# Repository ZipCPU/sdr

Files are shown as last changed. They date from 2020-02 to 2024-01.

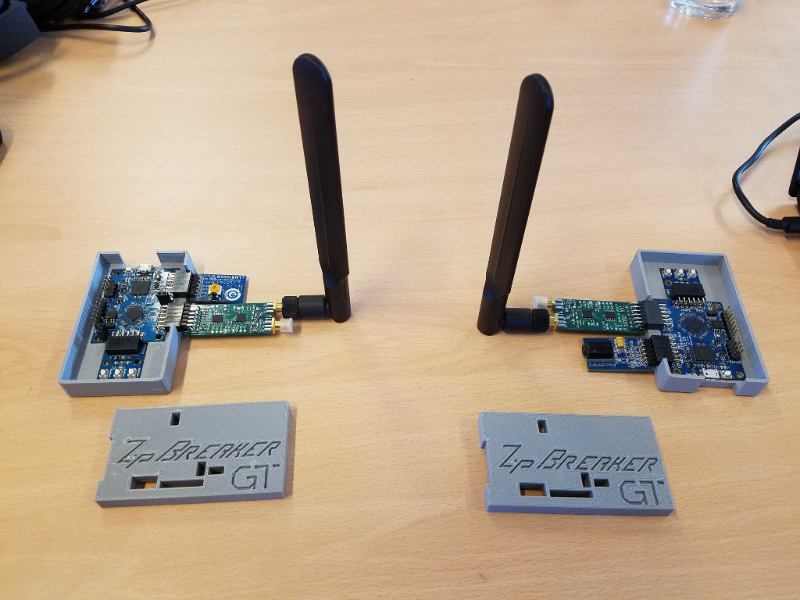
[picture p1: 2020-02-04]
doc/radio-set.jpg

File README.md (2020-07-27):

# A Software Defined Radio Project for FPGAs

Okay, so ... FPGA designs aren't really software.  Perhaps this should more
appropriately be named a "Gateware Defined Radio" project--but that spoils the
idea.

The goal of this project is to build a gateware design that can transfer audio
from one radio to another.  The design is built around the
[icebreaker](https://github.com/icebreaker-fpga/icebreaker) FPGA board,
the [SX1257 Radio PMod](https://github.com/xil-se/SX1257-PMOD),
the [Digilent MEMS microphone](https://store.digilentinc.com/pmod-mic3-mems-microphone-with-adjustable-gain/)
and the [Digilent AMP2 PMod](https://store.digilentinc.com/pmod-amp2-audio-amplifier/).
You can see [a picture of this setup here](doc/radio-set.jpg).

## Building the design

This repository actually contains several designs.  There's an
[AM transmitter](rtl/amxmit.v),
an [FM transmitter](rtl/fmxmit.v),
a [QPSK transmitter](rtl/qpskxmit.v),
an [AM receiver](rtl/amdemod.v), an
[FM receiver](rtl/fmdemod.v), and a
[QPSK receiver](rtl/qpskrcvr.v).  There are also three composed  designs, which
compose the transmitter and receiver together for simulation (only) purposes.
Which design gets built into the repository
is controlled by which "RF" line in the [AutoFPGA
Makefile](autodata/Makefile) is uncommented.

To build, you'll first need [AutoFPGA](https://github.com/ZipCPU/autofpga)
installed and in your path.  You can then run `make autodata` to build the
[top level design](rtl/toplevel.v), [PCF](rtl/sdr.pcf),
[simulation](sim/main_tb.cpp), and [software data files](sw/regdefs.h).  From
here, `make rtl` will build the design, `make sim` will build the simulator,
and `make sw` will build the host support software.

Beware, if you use any of the composed simulations, such as the AM transmitter
followed by the AM demodulator, you will run into a problem where the
microphone and the amplifier are both attempting to use the same pins.  The
solution is not to build the composed (transmit/receive) design in rtl.
Instead, run `make rtl-sim` to build the full simulation.

## Running in Simulation

To run the design in simulation, simply run the `main_tb` file in the `sim/`
directory.  This isn't very useful at present, however, unless you add the
`-d` switch to turn on VCD file generation.  You can then examine all the
traces from within the design.

Be aware, the simulation has no channel model.  Outputs to the
[SX1257](https://github.com/xil-se/SX1257-PMOD)
are simply fed back into the simulation receiver.

## Running on hardware

To run the design on an icebreaker, you can load the design via
`sudo iceprog rtl/sdr.bin`.  Once you do that, you'll want to then run
`sw/netuart /dev/ttyUSB?` (replace with your serial port device).  At this
point, you can interact with your design using `wbregs`.  Perhaps more
importantly, you can interact with the registers on the
[SX1257](https://github.com/xil-se/SX1257-PMOD)
using the `rfregs`.  In particular, `txconfig.sh` will turn the transmitter
on, and set it up at 915MHz.

## Debugging within hardware

This design offers two methods for debugging: capturing traces, and capturing
histograms from within the data flow.  Two bits of the GPIO register (three
for the TX/RX composed simulations) control a tap point selection within the
design.  This tap point contains a CE signal, 32'bits of data, and 10 bits
of data for a histogram.

To record a trace from wtihin the hardware, map the signals you wish to capture
to a Wishbone Scope C++ file--such as [this one for the
microphone](sw/micscope.cpp).  You can then use `wbregs rfscope 0` to reset
the scope any time you want to make a new capture, and
[micscope](sw/micscope.cpp) to extract the captured dasta and then to turn
it into a VCD file you can then analyze with GTKWave.

Alternatively, you can capture histograms from within the design.  These
can be read with the [histogram](sw/histogram.cpp) program.  This program will
also output a binary file of 32-bit integers containing your histogram.
(The
[histogram](https://zipcpu.com/dsp/2019/12/21/histogram.html)
is currently hardcoded at 1024 words, due to hardware limitations
in the iCE40 up5k.)

With a little creativity, the [histogram capture
utility](https://zipcpu.com/dsp/2019/12/21/histogram.html) can be turned into
a constellation capture utility.  By sending 5-bits of I and 5-bits of Q
into the histogram, and then interpreting the results accordingly, you can
capture (and then plot) a constellation diagram.  This is the purpose of
the [constellation](sw/constellation.cpp) program.

## Project Status

As of 20200204, ...

1. The AM receiver works when composed with the transmitter in simulation.
	The simulation has no channel model, is only so good, etc., etc.
	It's a start.
2. Both FM transmit/receive pair work when composed together in simulation.
3. The AM transmitter works, and the results can be heard using a Lime
	SDR radio receiver.  There's an annoying tone present which I haven't
	yet chased down.

As of 20200727, there's now a [QPSK transmitter](rtl/qpskxmit.v) and
[receiver](rtl/qpskrcvr.v) which both (roughly) work in simulation.  I say
roughly because the carrier tracking loop breaks lock even in simulation.
Further, the filters used in these designs are horrible block average types
of filters.  Hence, while the design can recover the incoming audio, there's
still lots of room for improvement.

## License

This project and all of its files are licensed under the GNU General
Public License, v3.

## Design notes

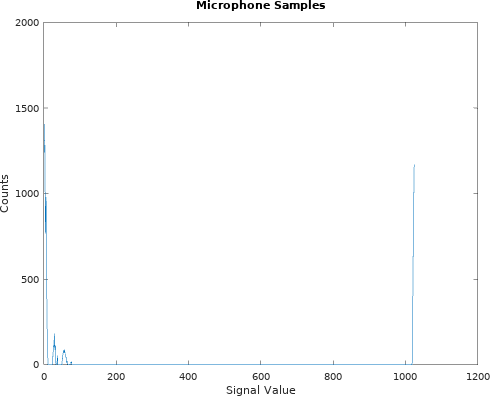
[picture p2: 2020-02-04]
doc/good-histogram.png

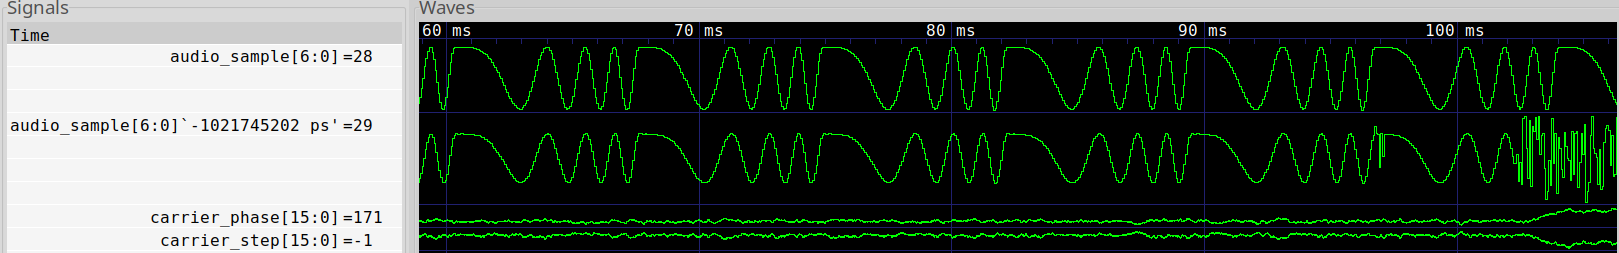
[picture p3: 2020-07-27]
doc/qpsk-matching-audio-lost-sync.png

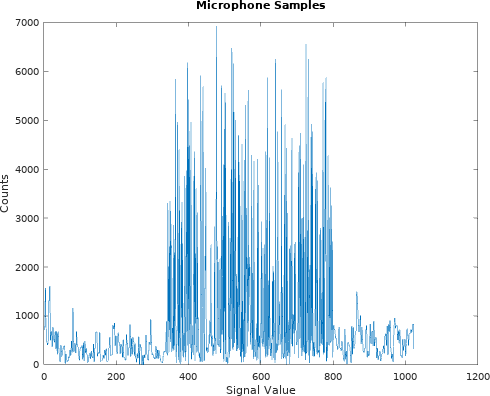
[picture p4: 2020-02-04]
doc/bad-hist-multimode.png

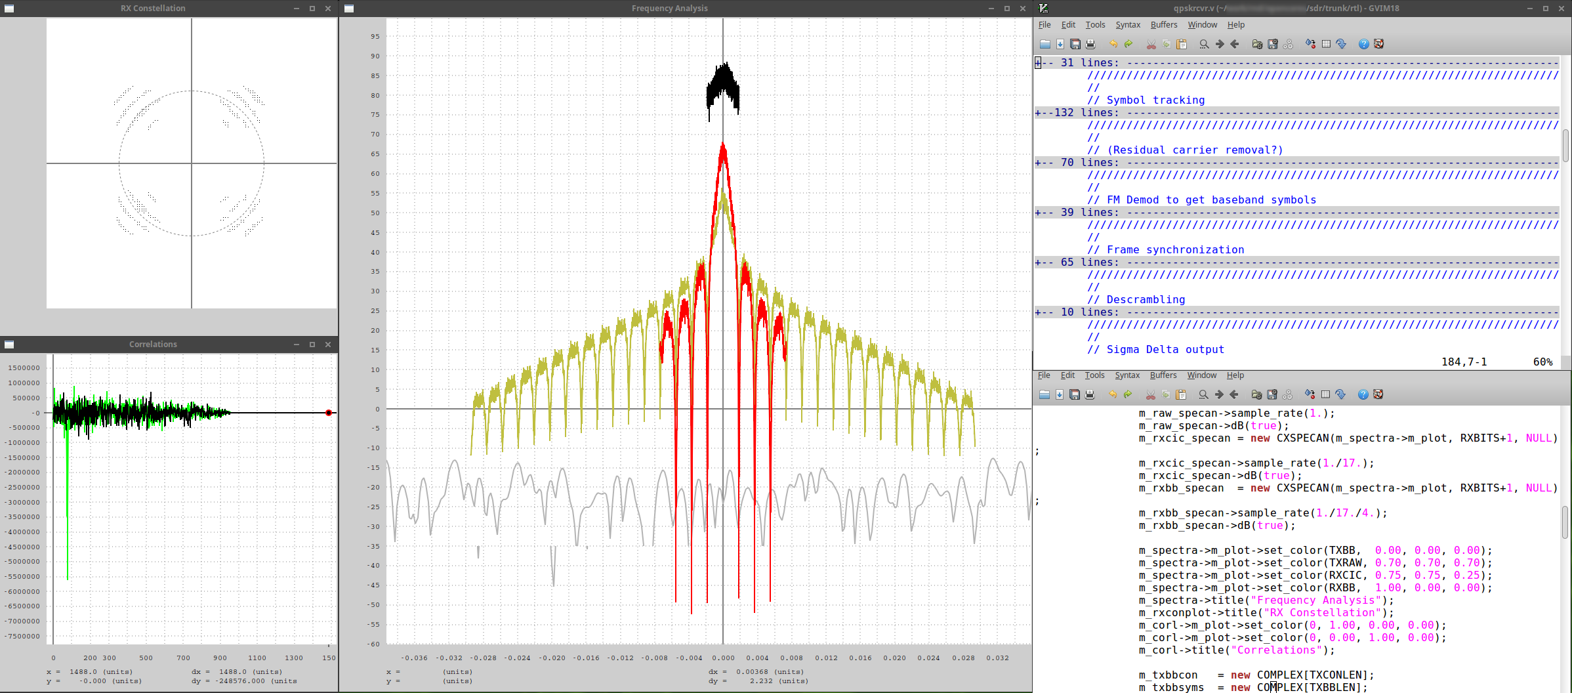
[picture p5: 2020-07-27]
doc/cooking-w-gas-screenshot.png

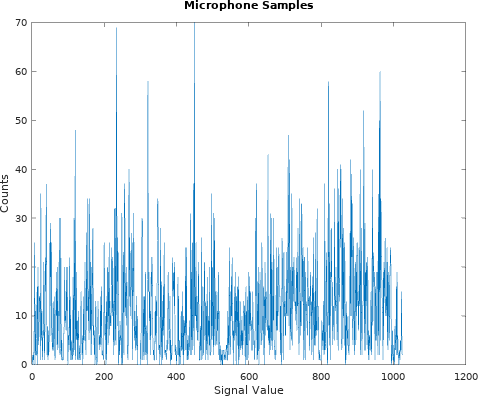
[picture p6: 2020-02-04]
doc/bad-histogram.png

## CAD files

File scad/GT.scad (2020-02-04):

module	GTlogo() {
	linear_extrude(height=5) {
		union() {
			polygon(points=[
				[10,14],
				[4,14],
				[0,10],
				[0,4],
				[4,0],
				[10,0],
				[12,2],
				[12,0],
				[14,0],
				[14,8],
				[8,8],
				[8,6],
				[12,6],
				[12,4],
				[10,2],
				[4,2],
				[2,4],
				[2,10],
				[4,12],
				[10,12] ]);
			polygon(points=[
				[18,0],
				[18,12],
				[12,12],
				[12,14],
				[20,14],
				[20,0] ]);
			polygon(points=[
				[22,14],
				[26,14],
				[26,12],
				[22,12] ]);
		}
	}
}
gtlogo_w = 26;
gtlogo_l = 14;
gtlogo_h = 5;

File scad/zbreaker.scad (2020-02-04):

include <zipcpu.scad>
include <zbreakerlogo.scad>
include <GT.scad>

module zbreaker() {
	// Top left is power, right side is the FMC connector
	raw_length = 36.95;
	raw_width  = 72.89;
	raw_base_width = 49.93;
	//
	raw_subboard_length = 20.55;
	//
	// The extra 2.4 is to get above the tops of the wire connectors
	raw_height_above_board = 4.6 + 1.5 + 2.4;
	zh = 2;
	tol = 0.1;
	
	case_width  = 85;	// Must be greater than 5.5*2 + raw_width
	case_length = 50;
	subbase_height = 5;

	bx = (case_width-raw_width)/2;
	by = (case_length-raw_length)/2;

	rad = 2;
	lip=2;

	module cutout(x, y, w, h, v) {
		ex = 1.5;
		translate([x-ex/2,y-ex/2,-tol/2])
			cube([w+ex,h+ex,v+tol]);
	}

	module keepit(x, y, w, h, v) {
		ex = -1.5;
		translate([x-ex/2,y-ex/2,-tol/2])
			cube([w+ex,h+ex,v+tol]);
	}

	module	subbase() {
		ex = 0.8;
		lipsm = lip-ex/2;
		shelf=3;
		total_height = subbase_height + raw_height_above_board;
		difference() {
			// A big case shell to start with
			translate([0,0,-subbase_height])
				color("red")
				cube([case_width, case_length, total_height-0.1]);

			//
			// Carve out the inside
			//
			translate([lipsm,lipsm,-0.1])
				cube([case_width-2*lipsm, case_length-2*lipsm, raw_height_above_board+0.1]);

			//
			// Cutouts for the board itself
			translate([bx-ex/2,by-ex/2,-1.6])
				cube([raw_base_width+ex, raw_length+ex, 1.7+2*lipsm]);
			translate([bx-ex/2,by+(raw_length-raw_subboard_length)/2-ex/2,-1.6])
				cube([raw_width+ex,raw_subboard_length+ex,1.7+2*lipsm]);

			//
			// Cut outs for the solder points under the board
			translate([bx+4.88,by,-3.1])
				cube([38.74+ex, 8.01, 3.2]);
			translate([bx+4.88-ex/2,by+31.05,-3.1])
				cube([38.74+ex, raw_length-31.05, 3.2]);
			translate([bx-ex/2+40,
				by+(raw_length-raw_subboard_length)/2-ex/2+shelf,-3.1])
				cube([(raw_width-40)+ex-shelf,raw_subboard_length+ex-2*shelf,3.2]);

			// A cutout underneath the board, USB plug side
			translate([bx-ex/2, by-ex/2+shelf,-3.1])
				cube([10,raw_length+ex-2*shelf,3.2]);

			// Cutout underneath main board, opposite USB side
			translate([bx+raw_base_width-10, by-ex/2+shelf,-3.1])
				cube([10+ex/2,raw_length+ex-2*shelf,3.2]);


			//
			// Cut in, near the USB plug
			translate([0,0,-subbase_height-0.1])
				cutout(0,by+6.0,bx-2.5,19,subbase_height+0.1+2*lip);
			// USB plug cutout in the lip
			translate([0,0,0])
				cutout(0,by+6.0,bx+2*lipsm,19,subbase_height+0.1+2*lipsm);
			// PMOD cutout in the lip
			translate([0,0,0])
				cutout(0,by+6.0,bx+2*lipsm,19,total_height+0.1);
			translate([bx,by,0]) {
				cutout(5.5, 30.5,
					28.8+15.7-5.5,
					case_length-30.5,total_height+0.1);
			}


			//
			// Corner cutouts so we can round the corners (later)
			translate([-0.1,-0.1,-subbase_height-0.1])
				cube([rad+0.1,rad+0.1,total_height+0.2]);
			translate([case_width-rad,-0.1,-subbase_height-0.1])
				cube([rad+0.1,rad+0.1,total_height+0.2]);
			translate([-0.1,case_length-rad,-subbase_height-0.1])
				cube([rad+0.1,rad+0.1,total_height+0.2]);
			translate([case_width-rad,case_length-rad,-subbase_height-0.1])
				cube([rad+0.1,rad+0.1,total_height+0.2]);
		}

		difference() {
			// Round all the corners
			union() {
			// First, fill the corners with cylinders
			translate([rad,rad,-subbase_height])
				cylinder(h=total_height,r=rad);
			translate([case_width-rad,rad,-subbase_height])
				cylinder(h=total_height,r=rad);
			translate([case_width-rad,case_length-rad,-subbase_height])
				cylinder(h=total_height,r=rad);
			translate([rad,case_length-rad,-subbase_height])
				cylinder(h=total_height,r=rad);
			}

			// Then remove the inner parts of the cylinders where
			// they'd interfere with the board
			translate([lipsm,lipsm,-0.1])
				cube([case_width-2*lipsm, case_length-2*lipsm, raw_height_above_board+0.1]);
		}
	}

	module layer(n) {
		base = (n==0) ? 0
			: (n == 1) ? 1.6
			: (n == 2) ? 3.0
			: (n == 3) ? 4.7
			: raw_height_above_board;

		ztmp = (n==0) ? 1.6
			: (n == 1) ? 3.0
			: (n == 2) ? 4.7
			: raw_height_above_board;

		zh = ztmp - base;
		translate([bx,by,base]) {
			// RGB - Double pin header
			cutout(11.2,6.1-5.1,10.04,4.6,raw_height_above_board);
			// Flash - Single pin header
			cutout(41.60-17.6,3.35-2.5,17.60,2.0,raw_height_above_board);
			// Cut in, near the USB plug
			cutout(-bx,6.0,bx-2.5,19,zh);

			// 5V top (between PMods)
			//
			// 4.8 x 2.5
			cutout(23.81,31.28,2.5,5.5,raw_height_above_board+0.1);
			// 5V (right)
			cutout(44.25,6,5.5,2.5,raw_height_above_board+0.1);
			// CRESET header
			cutout(39,5.7,2.5,5.5,raw_height_above_board+0.1);

			// pad platform
			if (n == 0) {
				difference() {
					color("black") {
						translate([-0.4,-0.4,0])
						cube([raw_width+0.8,raw_length+0.8,zh]);
					}

					// The sub board
					keepit(59,0,66-59,15.7,zh);
					keepit(59,24,66-59,15.7,zh);

					// The tearoff point
					keepit(50-0.75+0.4,0,2+1.5-0.8,raw_length,zh);

					// Screws
					// cutout(0,0,6,6,zh);
					// cutout(raw_width-6,0,6,6,zh);
					// cutout(raw_width-6,raw_length-6,6,6,zh);
					// cutout(0,raw_length-6,6,6,zh);

					// Pins on the left
					// keepit(-2,68.88-34.0,2.78+2,34.0,zh);
				}
			}

			if (n <= 1) {
				// @ 2.8mm, buttons on the end
				cutout(66.2,10.4,4.74,17.22,zh);
				// Button at the beginning
				cutout(-bx,7.8,bx+4.25,4.25,zh);
				// USB plug
				cutout(-bx,14.95,bx+5.1,7.7,zh);
			}
			//
			if (n <= 2) {
				// @ 4.6mm
				// Top Left PMod
				cutout(5.5,30.5,15.7,13.85,zh);
				// Top Right PMod
				cutout(28.8,30.5,15.7,13.85,zh);
				// Right edge PMod
				cutout(44,11,13.85,15.7,zh);

			}
		}
	}

	module	embossZip() {
		s = 1.0;
		depth = 1.5;
		translate([case_width/2, case_length/2, s*zlogoh/2+depth]) {
			rotate([0,180,180]) scale([s,s,1]) {
				translate([-zlogow/2,(zlogob-zlogol)/2,
							-zlogoh/2])
						zipcpulogo();
			}
		}
	}

	module	embossGT() {
		s = 0.8;
		margin=4;
		depth = 1.5;
		translate([case_width-gtlogo_w*s/2-margin, margin+gtlogo_l*s/2,
			   raw_height_above_board+gtlogo_h/2-depth]) {
			rotate([0,0,0]) scale([s,s,1]) {
				translate([-gtlogo_w/2,
						(-gtlogo_l)/2,
							-gtlogo_h/2])
						GTlogo();
			}
		}
	}

	module	embossGT2() {
		s = 0.8;
		margin=4;
		depth = 1.5;
		translate([case_width-gtlogo_w*s/2-margin, case_length-margin-gtlogo_l*s/2,
			   -subbase_height-gtlogo_h/2+depth]) {
			rotate([0,180,180]) scale([s,s,1]) {
				translate([-gtlogo_w/2,
						(-gtlogo_l)/2, -gtlogo_h/2])
					GTlogo();
			}
		}
	}

	module	embossZipBreaker() {
		s = 1.4;
		depth = 1.5;
		translate([case_width/2+2, case_length/2,
			   raw_height_above_board+zblogoh/2-depth]) {
			rotate([0,0,0]) scale([s,s,1]) {
				translate([-zblogow/2,
						(-zblogol)/2,
							-zblogoh/2])
						zbreakerlogo();
			}
		}
	}

	lipw = lip+0.4;
	if(1){
	rotate([180,0,0]) translate([0,-case_length,-raw_height_above_board])
	difference() {
		translate([lipw,lipw,0])
			cube([case_width-2*lipw,case_length-2*lipw,raw_height_above_board]);

		/*
		// Remove the corners
		translate([-0.1,-0.1,-0.1])
			cube([rad+0.1,rad+0.1,raw_height_above_board+0.2]);
		translate([case_width-rad,-0.1,-0.1])
			cube([rad+0.1,rad+0.1,raw_height_above_board+0.2]);
		translate([-0.1,case_length-rad,-0.1])
			cube([rad+0.1,rad+0.1,raw_height_above_board+0.2]);
		translate([case_width-rad,case_length-rad,-0.1])
			cube([rad+0.1,rad+0.1,raw_height_above_board+0.2]);
		*/

		// Detailed layers
		layer(0);
		layer(1);
		layer(2);
		layer(3);
		embossZipBreaker();
		embossGT();
		// embossBlackIce2();
		// For matching, remove the screw holes
		// screw_height = 4;
		// cutout(0,0,6.5,6.5,screw_height);
		// cutout(raw_width-6.5,0,6.5,6.5,screw_height);
		// cutout(raw_width-6.5,raw_length-6.5,6.5,6.5,screw_height);
		// cutout(0,raw_length-6.5,6.5,6.5,screw_height);
	}}

	if (1) { translate([0,case_length+10,subbase_height]) {
		difference() {
			subbase();
			translate([0,0,-2*subbase_height]) {
				embossZip();
			}
			embossGT2();
		}
	}}
}

zbreaker();

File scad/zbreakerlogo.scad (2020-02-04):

zblogow = 52;
zblogol = 8;
zblogob = 2;
zblogoh = 5;
module	zbreakerlogo() {
	linear_extrude(height=zblogoh) {
		union() {
			// Z
			polygon(points=[
				[0,0],
				[4,0],
				[5,1],
				[2,1],
				[9,8],
				[3,8],
				[2,7],
				[7,7] ]);
			// Dot on the 'i'
			polygon(points=[
				[5,2],
				[6,2],
				[7,3],
				[6,3] ]);
			// The 'p'
			polygon(points=[
				[3,-2],
				[4,-2],
				[8,2],
				[11,2],
				[10,1],
				[8,1],
				[7,0],
				[10,0],
				[12,2],
				[12,3],
				[8,3] ]);
			// The B
			polygon(points=[
				[12,0],
				[13,0],
				[19,6],
				[22,6],
				[20,4],
				[18,4],
				[17,3],
				[18,3],
				[18,2],
				[17,1],
				[15,1],
				[14,0],
				[17,0],
				[19,2],
				[19,3],
				[20,3],
				[23,6],
				[23,7],
				[19,7] ]);
			// R
			polygon(points=[
				[18,0],
				[19,0],
				[23,4],
				[25,4],
				[24,3],
				[23,3],
				[22,2],
				[22,0],
				[23,0],
				[23,2],
				[24,2],
				[26,4],
				[26,5],
				[23,5] ]);
			// E
			polygon(points=[
				[24,0],
				[28,0],
				[29,1],
				[26,1],
				[27,2],
				[28,2],
				[29,3],
				[28,3],
				[29,4],
				[32,4],
				[33,5],
				[29,5]]);
			// A
			polygon(points=[
				[29,0],
				[30,0],
				[34,4],
				[36,4],
				[35,3],
				[34,3],
				[33,2],
				[34,2],
				[32,0],
				[33,0],
				[37,4],
				[37,5],
				[34,5]]);
			// K
			polygon(points=[
				[34,0],
				[35,0],
				[37,2],
				[38,2],
				[38,1],
				[37,0],
				[38,0],
				[39,1],
				[39,2],
				[42,5],
				[41,5],
				[39,3],
				[38,3],
				[40,5],
				[39,5] ]);
			// E
			translate([15,0,0])
			polygon(points=[
				[24,0],
				[28,0],
				[29,1],
				[26,1],
				[27,2],
				[28,2],
				[29,3],
				[28,3],
				[29,4],
				[32,4],
				[33,5],
				[29,5]]);
			// R
			translate([44-18,0,0])
			polygon(points=[
				[18,0],
				[19,0],
				[23,4],
				[25,4],
				[24,3],
				[23,3],
				[22,2],
				[22,0],
				[23,0],
				[23,2],
				[24,2],
				[26,4],
				[26,5],
				[23,5] ]);
		}
	}
}

// zbreakerlogo();
// translate([0,-zblogob,-zblogoh]) color("red") cube([zblogow, zblogol+zblogob, zblogoh]);

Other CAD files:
scad/zbsolder.scad
scad/zipcpu.scad

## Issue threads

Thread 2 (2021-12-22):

I and Q bit-stream synchronization

elektronika-ba, 2021-12-22:
Hi,

How is the synchronization of I and Q bit-streams done? Reading through the datasheet I don't see any way of doing that.

Is it assumed that after configuring the SX1257 into RX or TX mode, the bit-stream starts and that is the synchronization?

Also, what is the format of I and Q values after receiving? - Is it the middle value 255/2 = no signal value?

Thanks

ZipCPU, 2021-12-22:
> How is the synchronization of I and Q bit-streams done? Reading through the datasheet I don't see any way of doing that.

On transmit, there's a clock.  On RX the bit streams are just way over sampled in the first place.  You could use the clock, I didn't.

> Also, what is the format of I and Q values after receiving? - Is it the middle value 255/2 = no signal value?

I&Q values are just +/- 1.  It's not a very capable receiver.

Dan

elektronika-ba, 2021-12-23:
I was trying to relate this to SDR and how we are getting IQ samples from them. I know that we are getting samples as 8 bits for "I" and 8 bits for "Q" where value of 0xFF/2 corresponds to "no RF signal value".

From the SX1257 (and SX1255) datasheet the IQ samples are just getting dumped out like crazy, without beginning or end. Then I opened my eyes and saw that this is an output from 1-bit sigma delta, meaning that we don't have data at this stage which is packed or organized in some form for processing, like we get them from RTL-SDR devices.

My assumption was wrong and I need to go back to the drawing board regarding my project with SX125x.

Looks like I need to look at your code even further, but now with a different mindset.

ZipCPU, 2021-12-23:
> Is there an implementation in your code that would calculate, for example, RSSI of the received signal?

No, there is no RSSI indicator.  A nearby histogram is available if necessary  for something like that if necessary.

Dan

Closed 2021-12-23.

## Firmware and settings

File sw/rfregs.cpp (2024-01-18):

////////////////////////////////////////////////////////////////////////////////
//
// Filename:	rfregs.cpp
// {{{
// Project:	SDR, a basic Soft(Gate)ware Defined Radio architecture
//
// Purpose:	
//
// Creator:	Dan Gisselquist, Ph.D.
//		Gisselquist Technology, LLC
//
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
// This program is distributed in the hope that it will be useful, but WITHOUT
// ANY WARRANTY; without even the implied warranty of MERCHANTIBILITY or
// FITNESS FOR A PARTICULAR PURPOSE.  See the GNU General Public License
// for more details.
//
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
////////////////////////////////////////////////////////////////////////////////
//
// }}}
#include <signal.h>
#include <stdint.h>
#include <time.h>
#include <unistd.h>
#include <strings.h>
#include <ctype.h>
#include <string.h>
#include <assert.h>
#include <stdlib.h>

#include "port.h"
#include "regdefs.h"
#include "hexbus.h"


#define	SLAVE_ADDRESS	0x50
#define	MASTER_WR	0
#define	MASTER_RD	1
#define	RF_I2C_WRITE	SLAVE_ADDRESS | MASTER_WR
#define	RF_I2C_READ	SLAVE_ADDRESS | MASTER_RD

const	int	MAX_I2C_RETRIES = 1;

#define	RF_REGMODE		0x00
#define	RF_REGFRFRXMSB		0x01
#define	RF_REGFRFRXMIB		0x02
#define	RF_REGFRFRXLSB		0x03
#define	RF_REGFRFTXMSB		0x04
#define	RF_REGFRFTXMIB		0x05
#define	RF_REGFRFTXLSB		0x06
#define	RF_REGTXGAIN		0x08
#define	RF_REGTXBW		0x0a
#define	RF_REGTXDACBW		0x0b
#define	RF_REGRXANAGAIN		0x0c
#define	RF_REGRXBW		0x0d
#define	RF_REGRXPLLBW		0x0e
#define	RF_REGDIOMAPPING	0x0f
#define	RF_REGCLKSELECT		0x10
#define	RF_REGMODESTATUS	0x11
#define	RF_REGLOWBATTHRESH	0x1a

#define	RF_SPI_WRITE		0x01
#define	RF_SX_RESETW		0x01
#define	RF_SPI_MODE_FN		0xf0
#define	RF_IDLE_MODE_FN		0xf2
#define	RF_GPIO_WRITE_FN	0xf4
#define	RF_GPIO_READ_FN		0xf5
#define	RF_GPIO_ENABLE_FN	0xf6
#define	RF_GPIO_CONFIG_FN	0xf7
//
#define	RF_SPI_CONFIG		0x01	// MSB first, CPOL=0,CPHA=0, 461kHz
#define	RF_GPIO_ENABLE_CONFIG	0x02	// SX RESET is GPIO pin #1
// #define	RF_GPIO_CONFIG		0xa5	// Push/pull on 0-1, 'bz on 2-3
#define	RF_GPIO_CONFIG		0xa5	// Push/pull on 0-1, 'bz on 2-3

	////////////////////////////////////////////////////////////////////////
	//
	//
typedef	struct	{
	unsigned	rf_addr, rf_bytes;
	const char	*rf_name;
} RFNAME;

#define	RFREGS	15
RFNAME rfregs[RFREGS] = {
	RF_REGMODE,         1, "RegMode",
	RF_REGFRFRXMSB,     3, "FRFRX",
	RF_REGFRFTXMSB,     3, "FRFTx",
	RF_REGTXGAIN,       1, "TxGain",
	RF_REGTXBW,         1, "TxBandwidth",
	RF_REGTXBW,         1, "TxBW",
	RF_REGTXDACBW,      1, "TxDACBandwidth",
	RF_REGRXANAGAIN,    1, "RxAnalogGain",
	RF_REGRXBW,         1, "RxBandwidth",
	RF_REGRXBW,         1, "RxBW",
	RF_REGRXPLLBW,      1, "RxPLLBW",
	RF_REGDIOMAPPING,   1, "DioMapping",
	RF_REGCLKSELECT,    1, "ClkSelect",
	RF_REGMODESTATUS,   1, "ModeStatus",
	RF_REGLOWBATTHRESH, 1, "LowBatThresh"
};

unsigned	rfaddrdecode(const char *v) {
	if (isalpha(v[0])) {
		for(int i=0; i<RFREGS; i++)
			if (strcasecmp(v, rfregs[i].rf_name)==0)
				return rfregs[i].rf_addr;
		fprintf(stderr, "Unknown register: %s\n", v);
		exit(-2);
	} else
		return strtoul(v, NULL, 0);
}

const char *rfaddrname(const unsigned v) {
	for(int i=0; i<RFREGS; i++)
		if (rfregs[i].rf_addr == v)
			return rfregs[i].rf_name;
	return NULL;
}

unsigned	rfaddrbytes(const unsigned v) {
	for(int i=0; i<RFREGS; i++)
		if (rfregs[i].rf_addr == v)
			return rfregs[i].rf_bytes;
	return 1;
}

	////////////////////////////////////////////////////////////////////////
	//
	//

// define	RF_SX_RESETR	0x53

#define	SCL_BIT		1
#define	SDA_BIT		2

#define	SCL_INPUT	(SCL_BIT << 16)
#define	SDA_INPUT	(SDA_BIT << 16)

#define	SET_GPIO(A)	((A<<16)|A)
#define	CLR_GPIO(A)	(A<<16)

#define	SDA_OFF(A)	A->writeio(R_GPIO, CLR_GPIO(SDA_BIT))
#define	SDA_ON(A)	A->writeio(R_GPIO, SET_GPIO(SDA_BIT))

#define	SCL_OFF(A)	A->writeio(R_GPIO, CLR_GPIO(SCL_BIT))
#define	SCL_ON(A)	A->writeio(R_GPIO, SET_GPIO(SCL_BIT))

void	i2c_start(FPGA *m_fpga) {
	// {{{
	SDA_OFF(m_fpga);
	m_fpga->readio(R_GPIO);
	SCL_OFF(m_fpga);
	// }}}
}

void	i2c_stop(FPGA *m_fpga) {
	// {{{
	SDA_OFF(m_fpga);
	m_fpga->readio(R_GPIO);
	SCL_ON(m_fpga);
	m_fpga->readio(R_GPIO);
	SDA_ON(m_fpga);
	// }}}
}

int	i2c_read_byte(FPGA *m_fpga, int ack = 1) {
	// {{{
	int	result = 0, v;

	SDA_ON(m_fpga);
	for(int k=0; k<8; k++) {
		SCL_ON(m_fpga);
		do {
			v = m_fpga->readio(R_GPIO);
		} while((v & SCL_INPUT) == 0);
		
		result = (result << 1)
			| ((m_fpga->readio(R_GPIO) & SDA_INPUT) ? 1:0);
		SCL_OFF(m_fpga);
	}

	if (ack)
		SDA_OFF(m_fpga);
	SCL_ON(m_fpga);
	do {
		v = m_fpga->readio(R_GPIO);
	} while((v & SCL_INPUT) == 0);
	SCL_OFF(m_fpga);
	SDA_ON(m_fpga);

	return result;
	// }}}
}

int	i2c_write_byte(FPGA *m_fpga, unsigned byte) {
	// {{{
	int	v;

	for(int k=0; k<8; k++) {
		if (byte & (128 >> k)) {
			// fprintf(stderr, "WRITE BIT[%d] = 1\n", 7-k);
			SDA_ON(m_fpga);
		} else {
			// fprintf(stderr, "WRITE BIT[%d] = 0\n", 7-k);
			SDA_OFF(m_fpga);
		}
		SCL_ON(m_fpga);
		do {
			v = m_fpga->readio(R_GPIO);
		} while((v & SCL_INPUT) == 0);

		if (((v & SDA_BIT)==0) && ((byte & (128 >> k))!=0)) {
			fprintf(stderr, "ERR GPIO = %05x\n", v);
			return 1;
		}
		SCL_OFF(m_fpga);
	}

	SDA_ON(m_fpga);
	m_fpga->readio(R_GPIO);
	SCL_ON(m_fpga);
	do {
		v = m_fpga->readio(R_GPIO);
	} while((v & SCL_INPUT) == 0);
	SCL_OFF(m_fpga);

	if ((v & SDA_INPUT)!=0)
		return 1;
	return 0;
	// }}}
}

int	i2c_read(FPGA *m_fpga, int msglen, char *msg) {
	// {{{
	int	retries = 0;
	int	err = 0;

	do {
		i2c_start(m_fpga);
		err = i2c_write_byte(m_fpga, RF_I2C_READ);
		if (err)
			printf("I2C: RETRY-READ\n");
	} while(err && ++retries < MAX_I2C_RETRIES);

	if (err) {
		i2c_stop(m_fpga);
		return 1;
	}

	for(int k=0; !err && (k<msglen-2); k++)
		msg[k] = i2c_read_byte(m_fpga);
	if (!err)
		msg[msglen-2] = i2c_read_byte(m_fpga, 0);
	i2c_stop(m_fpga);

	return 0;
	// }}}
}

int	i2c_write(FPGA *m_fpga, int msglen, char *msg) {
	// {{{
	int	retries = 0;
	int	err = 0;

	do {
		i2c_start(m_fpga);
		err = i2c_write_byte(m_fpga, (RF_I2C_WRITE));
		if (err)
			printf("I2C: RETRY-WRITE\n");
	} while(err && ++retries < MAX_I2C_RETRIES);
	if (err) {
		i2c_stop(m_fpga);
		return 1;
	}

	for(int k=0; !err && k<msglen; k++)
		err |= i2c_write_byte(m_fpga, msg[k]);
	i2c_stop(m_fpga);

	return err;
	// }}}
}


unsigned	read_rfreg(FPGA *m_fpga, unsigned addr, unsigned  count = 1) {
	// {{{
	char		msg[32];
	int		msglen = 0;
	unsigned	result;

	msg[msglen++] = RF_SPI_WRITE;
	msg[msglen++] = addr & 0x07f; // Leave the top bit clear for a read
	for(int k=0; k<(int)count && (msglen < 32); k++)
		msg[msglen++] = 0;
	i2c_write(m_fpga, msglen, msg);

	for(int k=0; k<msglen+2; k++)
		msg[k] = 0;

	i2c_read(m_fpga, msglen, msg);

	result = 0;
	for(int k=0; k<(int)count; k++)
		result = (result << 8) | (msg[1+k] & 0x0ff);
	return result;
	// }}}
}

void	write_rfreg(FPGA *m_fpga, unsigned addr, unsigned value, int count=1) {
	// {{{
	char		msg[32];
	int		msglen = 0;

	msg[msglen++] = RF_SPI_WRITE;
	msg[msglen++] = addr | 0x80; // Set the top bit for a write
	for(int k=0; k<count && (msglen < 32); k++)
		msg[msglen++] = (value >> (count-1-k)*8);;

	i2c_write(m_fpga, msglen, msg);
	// }}}
}

void	rf_config(FPGA *m_fpga) {
	// {{{
	char	msg[32];
	int	msglen;

/*
	msg[0] = RF_SPI_MODE_FN;
	msg[1] = RF_SPI_CONFIG;
	msglen = 2;

	i2c_write(m_fpga, msglen, msg);
*/

	msg[0] = RF_GPIO_ENABLE_FN;
	msg[1] = RF_GPIO_ENABLE_CONFIG;
	msglen = 2;

	i2c_write(m_fpga, msglen, msg);

/*
	msg[0] = RF_GPIO_CONFIG_FN;
	msg[1] = RF_GPIO_CONFIG;
	msglen = 2;

	//
	// Toggle the SX_RESET pin high
	//
	i2c_write(m_fpga, msglen, msg);

	msg[0] = RF_GPIO_WRITE_FN;
	msg[1] = 0x02;
	msglen = 2;

	i2c_write(m_fpga, msglen, msg);

*/
	// And low again
	msg[0] = RF_GPIO_WRITE_FN;
	msg[1] = 0x00;
	msglen = 2;

	i2c_write(m_fpga, msglen, msg);

/*
	//
	// Set the reset to high impedence
	//
	msg[0] = RF_GPIO_CONFIG_FN;
	msg[1] = 0xa9;
	msglen = 2;

	i2c_write(m_fpga, msglen, msg);
*/
	// }}}
}

FPGA	*m_fpga;
void	closeup(int v) {
	m_fpga->kill();
	exit(0);
}

bool	isvalue(const char *v) {
	// {{{
	const char *ptr = v;

	while(isspace(*ptr))
		ptr++;

	if ((*ptr == '+')||(*ptr == '-'))
		ptr++;
	if (*ptr == '+')
		ptr++;
	if (*ptr == '0') {
		ptr++;
		if (tolower(*ptr) == 'x')
			ptr++;
	}

	return (isdigit(*ptr));
	// }}}
}

void	usage(void) {
	printf("USAGE: rfregs [-d] address [value]\n");
}

int main(int argc, char **argv) {
	const char *host = FPGAHOST;
	int	port=FPGAPORT;
	bool	config_flag = false;
	int	skp;

	// Argument processing
	// {{{
	skp = 1;
	for(int argn=0; argn<argc-skp; argn++) {
		skp++;
		if (strcmp(argv[argn+skp-1],"-c")==0) {
			config_flag = true;
		} else {
			skp--;
			argv[argn] = argv[argn+skp];
		}
	} argc -= skp;
	// }}}

	m_fpga = new FPGA(new NETCOMMS(host, port));

	signal(SIGSTOP, closeup);
	signal(SIGHUP, closeup);

	if (config_flag) {
		rf_config(m_fpga);
		if (argc < 1)
			exit(EXIT_SUCCESS);
	}

	if ((argc < 1)||(argc > 2)) {
		usage();
		// printf("USAGE: rfregs address [value]\n");
		exit(EXIT_FAILURE);
	}

	const char *nm = NULL, *named_address = argv[0];
	unsigned address, value;

	if (isvalue(named_address)) {
		address = strtoul(named_address, NULL, 0);
		nm = rfaddrname(address);
	} else {
		address = rfaddrdecode(named_address);
		nm = rfaddrname(address);
	}

	if (NULL == nm)
		nm = "";

	if (argc < 2) { // Read a register
		// {{{
		FPGA::BUSW	v;
		try {
			unsigned char a, b, c, d, msglen;

			msglen = rfaddrbytes(address);
			v = read_rfreg(m_fpga, address, msglen);
			a = (v>>24)&0x0ff;
			b = (v>>16)&0x0ff;
			c = (v>> 8)&0x0ff;
			d = (v    )&0x0ff;

			printf("%08x (%8s) : [%c%c%c%c] %08x\n", address, nm, 
				isgraph(a)?a:'.', isgraph(b)?b:'.',
				isgraph(c)?c:'.', isgraph(d)?d:'.', v);

		} catch(BUSERR b) {
			printf("%08x (%8s) : BUS-ERROR\n", address, nm);
		} catch(const char *er) {
			printf("Caught bug: %s\n", er);
			exit(EXIT_FAILURE);
		}
		// }}}
	} else { // Write to a register
		// {{{
		try {
			value = strtoul(argv[1], NULL, 0);
			write_rfreg(m_fpga, address, value);
			printf("%08x (%8s)-> %08x\n", address, nm, value);
		} catch(BUSERR b) {
			printf("%08x (%8s) : BUS-ERR)R\n", address, nm);
			exit(EXIT_FAILURE);
		} catch(const char *er) {
			printf("Caught bug on write: %s\n", er);
			exit(EXIT_FAILURE);
		}
		// }}}
	}

	if (m_fpga->poll())
		printf("FPGA was interrupted\n");
	delete	m_fpga;
}

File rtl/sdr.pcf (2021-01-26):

set_io i_clk_12mhz	35
#
set_io o_ledr		11
set_io o_ledg		37
#
set_io i_btn[0]	10	## BUTTONn
set_io i_btn[1]	20	## P2_9
set_io i_btn[2]	19	## P2_4
set_io i_btn[3]	18	## P2_10
#
# FTDI
set_io i_host_uart_rx	6
set_io o_host_uart_tx	9
# set_io o_host_uart_cts_n
# set_io i_host_uart_rts_n
#
# PMod 1A bottom: MIC3
set_io o_mic_csn	 3	# SS    7 P1A7   3 ### Top was ... 1 P1A1  4
### NC - no connect
set_io i_mic_miso	46	# MISO 10 P1A9  46 ### Top was ... 3 P1A3 47
set_io o_mic_sck	44	# SCK   9 P1A10 44 ### Top was ... 4 P1A4 45
#
# PMod 1A bottom: AMP2 (5-6 are GND/VCC)
set_io o_pwm_audio	 3	# 1 P1A7   3
set_io o_pwm_gain	48	# 2 P1A8  48
### NC - no connect
set_io o_pwm_shutdown_n 44	# 4 P1A10 44
#
# Assuming sides ...
# PMod 1B
set_io o_rf_clk	32	# CLK_IN P1B9
set_io o_rf_data[0]	38	# Q-In P1B2
set_io o_rf_data[1]	43	# I-In P1B1
#
# set_io i_rf_clk	28	# CLK_OUT P1B10
# set_io i_rf_data[0]	34	# Q-Out P1B3
# set_io i_rf_data[1]	31	# I-Out P1B4
#
set_io io_i2c_scl	42	# I2C_CLK P1B7
set_io io_i2c_sda	36	# I2C_SDA P1B8
##

## Adding in any PCF_INSERT tags

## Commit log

2020-02-04 Added an (unused) lock pin on the output of the PLL
2020-02-04 Added GTKW sim files for viewing traces
2020-02-06 PCF corrected for missing (commented) clock pin, main for extra case default
    [sdr.pcf]
2020-07-18 Comments added to separate CIC filter sections
2020-07-19 [WIP] on QPSK, receive filter is still way off, no rcv baud spike yet
2020-07-20 Fixed extra comma in params, added block comments to CIC filter
2020-07-20 QPSK RX gain fixs: PLL + filters + resmpl filter ln fix
2020-07-20 Added: pulse shaping filter

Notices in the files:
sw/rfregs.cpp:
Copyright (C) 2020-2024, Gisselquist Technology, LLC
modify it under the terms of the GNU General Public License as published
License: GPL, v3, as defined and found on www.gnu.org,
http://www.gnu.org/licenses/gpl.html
